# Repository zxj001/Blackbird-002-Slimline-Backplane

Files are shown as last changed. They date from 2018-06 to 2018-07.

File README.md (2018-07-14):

# HP BlackBird 002 Slimline SATA Back Plane PCB

**Current Working Version: 0.4**

**Latest Stable Version: 0.3**

**Latest Physical Version: 0.2**

### To Do List
* Get SMD resistor specs and components
* Get SMD LED specs and components
* Reconfigure top LED section to account for SMD LED

### Wish List
* Research button for SATA
* Find a suitable button component

### Components

| Part Type | Part Number |
|---|---|
| SATA | 678007005 |
| 8981 Molex | 0015244745 |
| Slimline SATA | 1735539 |

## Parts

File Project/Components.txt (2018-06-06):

#####################################
MOUSER
	
Mouser #:	538-67800-7005
Mfr. #:	67800-7005
Desc.:	I/O Connectors I/O Connectors 1.27MM High Speed Co d Conn. Verticle L/F
4	$0.71	$2.84	
4 Shipped	10-May-18	48062753

Mouser #:	538-67800-8005
Mfr. #:	67800-8005
Desc.:	I/O Connectors I/O Connectors 7Ckt Vert Signal Hdr w/tabs locking latch
4	$0.61	$2.44	
4 Shipped	10-May-18	48062753

Mouser #:	538-67800-5005
Mfr. #:	67800-5005
Desc.:	I/O Connectors I/O Connectors 7Ckt Vert Signal Hdr SMT w/ locking latch
4	$0.66	$2.64	
4 Shipped	10-May-18	48062753

Mouser #:	538-15-24-4745
Mfr. #:	15-24-4745
Desc.:	Power to the Board Power to the Board HI TEMP VERT HDR lead free

#####################################
DIGIKEY

Index	Quantity	Cancelled	Quantity Shipped	Part Number	Description	Customer Reference	Backorder	Unit Price	Extended Price
1	5	0	5	1735539-2-SI-ND	SLIMLINE SATA RECPT VERTICAL SMT		0	1.68000	$8.40

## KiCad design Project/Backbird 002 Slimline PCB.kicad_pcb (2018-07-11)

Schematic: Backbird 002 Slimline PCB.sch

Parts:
D1: LED; LED_D1.8mm_W3.3mm_H2.4mm
Molex_4pin1: Conn_01x04; MOLEX_8981_0015244745
R1: R 3k; Resistor_SMD+THTuniversal_2512_RM10_HandSoldering
R2: R 1k; Resistor_SMD+THTuniversal_2512_RM10_HandSoldering
Sata_Data1: Conn_01x07; SATA_DATA_678007005_CustomPad
Sata_Slimline_Recpt1: Conn_01x13; SATA_SLIMLINE_RECPT_1735539-2
Screw_Hole_B1: Conn_01x01; Blackbird002_Slimline_PCB_Screw
Screw_Hole_T1: Conn_01x01; Blackbird002_Slimline_PCB_Screw_Long

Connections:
+5V: Molex_4pin1.4, R2.2, Sata_Slimline_Recpt1.9, Sata_Slimline_Recpt1.10
A+: Sata_Data1.2, Sata_Slimline_Recpt1.2
A-: Sata_Data1.3, Sata_Slimline_Recpt1.3
B+: Sata_Data1.6, Sata_Slimline_Recpt1.6
B-: Sata_Data1.5, Sata_Slimline_Recpt1.5
GND: D1.1 (K), Molex_4pin1.2, Molex_4pin1.3, R1.1, Sata_Data1.1, Sata_Data1.4, Sata_Data1.7, Sata_Slimline_Recpt1.1, Sata_Slimline_Recpt1.4, Sata_Slimline_Recpt1.7, Sata_Slimline_Recpt1.12, Sata_Slimline_Recpt1.13
unnamed: D1.2 (A), R1.2, R2.1

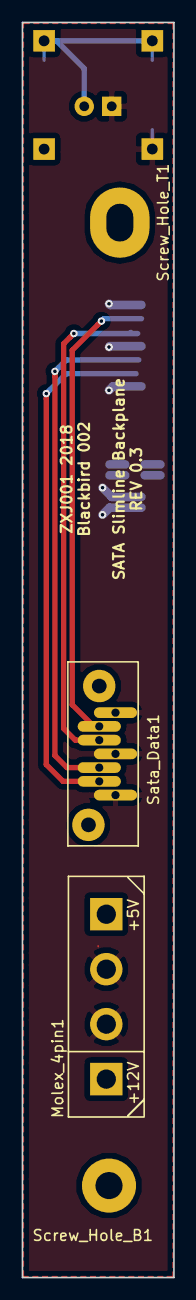
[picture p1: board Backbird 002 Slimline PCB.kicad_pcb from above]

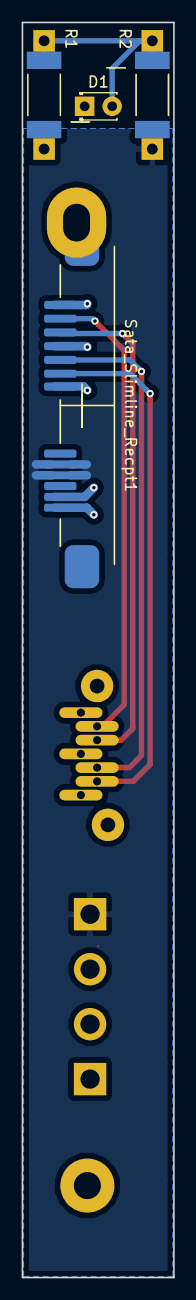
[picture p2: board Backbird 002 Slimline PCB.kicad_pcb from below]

Board: 2 copper layers, 14.0 x 116.0 mm, 8 parts (4 on the bottom side), 7 nets.

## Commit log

2018-06-01 Initial commit for a Sata Slimline backpane PCB
    [Backbird 002 Slimline PCB.kicad_pcb, Backbird 002 Slimline PCB.sch]
2018-06-06 moved files to new folder for organization
    [Backbird 002 Slimline PCB.kicad_pcb, Backbird 002 Slimline PCB.sch]
2018-06-07 added a spreadsheet to keep track of components
    [Backbird 002 Slimline PCB.kicad_pcb, Backbird 002 Slimline PCB.sch]
2018-06-07 Upgraded project to KiCad 5 RC2 nightly build (kicad-20180606-033155.9552e02-c4osx)
    [Backbird 002 Slimline PCB-2018-06-07-14-33-44.sch, Backbird 002 Slimline PCB-2018-06-07-14-34-42.sch, Backbird 002 Slimline PCB.sch]
2018-06-07 Fixed pinout of Sata data ports to be 7-pin instead of 6
    [Backbird 002 Slimline PCB.sch]
2018-06-07 Annotated schematic
    [Backbird 002 Slimline PCB.sch]
2018-06-08 Added Footprints for Molex Power, Sata Data, and Sata Slimline connectors.
2018-06-08 Added holes for blocking off the LED. Also added an additional connector for power
    [Backbird 002 Slimline PCB.sch]
2018-06-08 First pass at building the PCB using footprints. Fixed Sata Slimeline Recpt footprint by numbering the pins from 1-13 and adding mechanical pads. Made molex 8981 footprint cleaner by adding the notch.
    [Backbird 002 Slimline PCB.sch]
2018-06-08 Updated PSB layout. (might remove extra power and Sata locations) Added custom footprints for screws and for a generic 8981 power pinout.
    [Backbird 002 Slimline PCB.kicad_pcb, Backbird 002 Slimline PCB.sch]
2018-06-09 Removed extra connectors from PCB
    [Backbird 002 Slimline PCB.kicad_pcb, Backbird 002 Slimline PCB.sch]
2018-06-10 Fixed Sata Slimline footprint to have pads instead of holes. Moved Sata receptacle to the back side of the PCB
    [Backbird 002 Slimline PCB.kicad_pcb]
2018-06-10 Added elongated screw hole
    [Backbird 002 Slimline PCB.kicad_pcb]
2018-06-10 Moved LED and resistors to the back side of the PCB
    [Backbird 002 Slimline PCB.kicad_pcb]
2018-06-12 Moved silk screen of resistors and LED power holes to be on the PCB.
    [Backbird 002 Slimline PCB.kicad_pcb, Backbird 002 Slimline PCB.sch]
2018-06-14 Moved top drill hole and Sata Recpt into the correct positions. Edited the pads on the Sata Recpt footprint to be more accurate. Still need to add traces
    [Backbird 002 Slimline PCB.kicad_pcb]
2018-06-14 Improved trace widths and zone fills
    [Backbird 002 Slimline PCB.kicad_pcb]
2018-06-17 Connected top components
    [Backbird 002 Slimline PCB.kicad_pcb]
2018-06-22 Edited receptacle so that the origin of the pads are lower instead of in the center
    [Backbird 002 Slimline PCB.kicad_pcb]
2018-06-22 remove extra 2 holes for the LED section
    [Backbird 002 Slimline PCB.kicad_pcb, Backbird 002 Slimline PCB.sch]
2018-06-22 Updated silkscreen to include description
    [Backbird 002 Slimline PCB.kicad_pcb]
2018-06-23 Fix SATA padding by having the drill in the center of the pad to meet OSHPark's expectations.
    [Backbird 002 Slimline PCB.kicad_pcb]
2018-07-10 Moved bottom screw hole into correct position
    [Backbird 002 Slimline PCB.kicad_pcb]
2018-07-10 Changed hole size to 2.5mm from 3mm and total diameter from 6 to 5
2018-07-10 Updated screw hole on the PCB to the new footprint.
    [Backbird 002 Slimline PCB.kicad_pcb]
2018-07-11 Moved top screw hole closer to edge
    [Backbird 002 Slimline PCB.kicad_pcb]
2018-07-11 Shrank top (long) screw hole by 0.5mm on each dimension
    [Backbird 002 Slimline PCB.kicad_pcb]
2018-07-11 Moved 4pin power connector down ~3mm
    [Backbird 002 Slimline PCB.kicad_pcb]
2018-07-11 Traces are now at least 0.5mm wide. Added more traces for the +5V SATA power connector
    [Backbird 002 Slimline PCB.kicad_pcb]
2018-07-11 Moved data traces more inward so the power plane isn't cut off
    [Backbird 002 Slimline PCB.kicad_pcb]
2018-07-11 Added rev 0.3 text
    [Backbird 002 Slimline PCB.kicad_pcb]
2018-07-11 Refilled power planes. Adjusted traces for SATA connection. Added README file with component part numbers
    [Backbird 002 Slimline PCB.kicad_pcb]
